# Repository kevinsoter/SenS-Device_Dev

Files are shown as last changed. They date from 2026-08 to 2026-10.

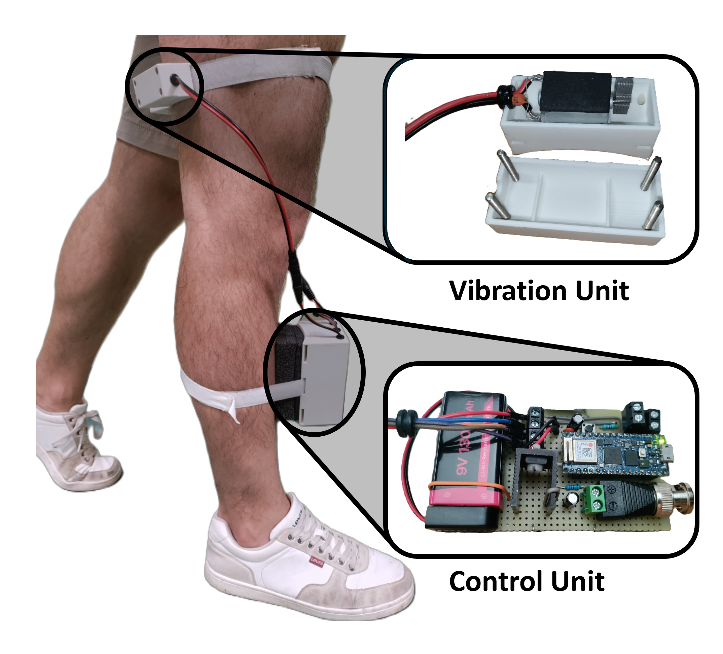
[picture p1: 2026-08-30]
images/SenS-Device.png

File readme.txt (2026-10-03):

A Compact Wearable Tendon Vibration Device for Dynamic Modulation of Proprioceptive Feedback

**Status: Development and validation manuscript in preparation**

This repository will host the open-source hardware, firmware, and design files for a wearable device developed to deliver controlled tendon vibration for eliciting the Tonic Vibration Reflex (TVR) and proprioceptive stimulation of muscle spindles. The device was designed to output vibration at defined frequencies and amplitudes suitable for TVR elicitation, and its development and validation are described in an accompanying manuscript currently in preparation.

## About the Project

Tendon vibration is a well-established technique for eliciting the Tonic Vibration Reflex and proprioceptive illusions by stimulating Ia afferents in muscle spindles. Reliable, low-cost, and reproducible hardware for delivering this stimulation in research appropriate ways is not widely available as an open resource, which motivated the development of this wearable.

The device is designed to:
- Deliver vibration within the frequency and amplitude ranges known to elicit TVR
- Be wearable and adjustable for placement over target tendons/muscle bellies
- Allow researchers to reproduce and adapt the stimulation parameters for their own protocols

Further technical detail, methodology, and validation data will be available once the manuscript is published.

## Planned Repository Contents

The following materials will be added as they are finalized and cleared for release:

- [ ] Paper abstract
- [x] Electronics schematics & routing files
- [x] Materials/Components used
- [x] Firmware (Arduino IDE, C++) for vibration frequency/amplitude Control
- [x] CAD files for the custom enclosure/casing (wearable housing)

## Current Status

| Component | Status |
|---|---|
| Device design | Complete |
| Firmware | Complete |
| Manuscript | In preparation |
| Schematics/CAD release | Pending |
| Validation dataset | Pending publication |

## Why Open Source?

Custom stimulation hardware is a common bottleneck for labs studying proprioception, motor control, and vibrotactile feedback. By releasing the full design, electronics, enclosure, and firmware we hope to lower the barrier for other groups to replicate, adapt, or build on this work.

---

*This README will be updated as the manuscript progresses and files are released. Last updated: [12.07.206].*

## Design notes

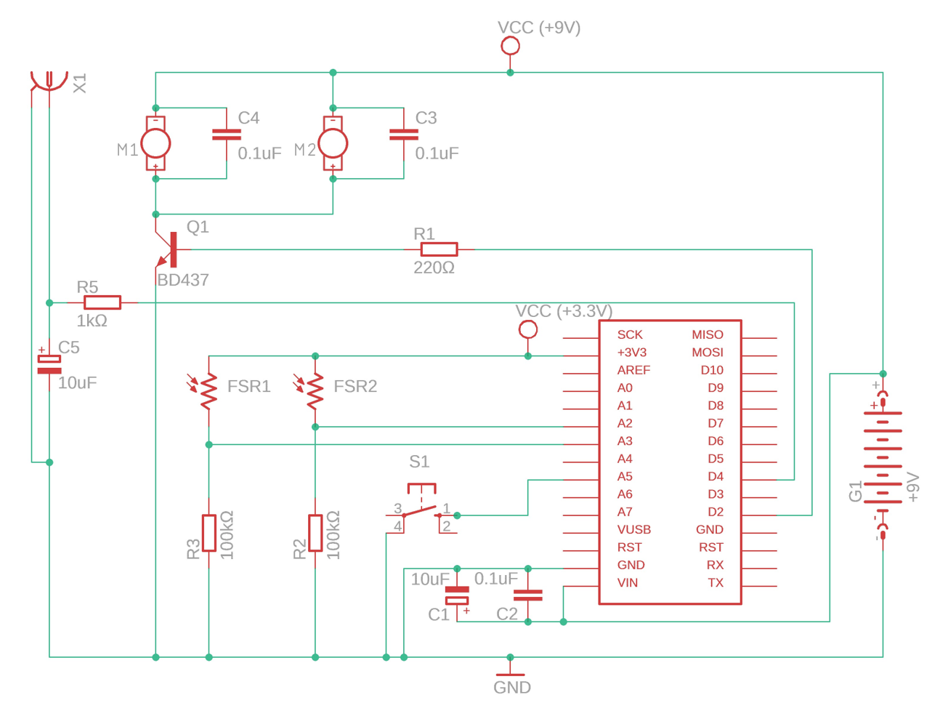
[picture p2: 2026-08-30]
hardware/electronics/SenS_Device_Schematics.png

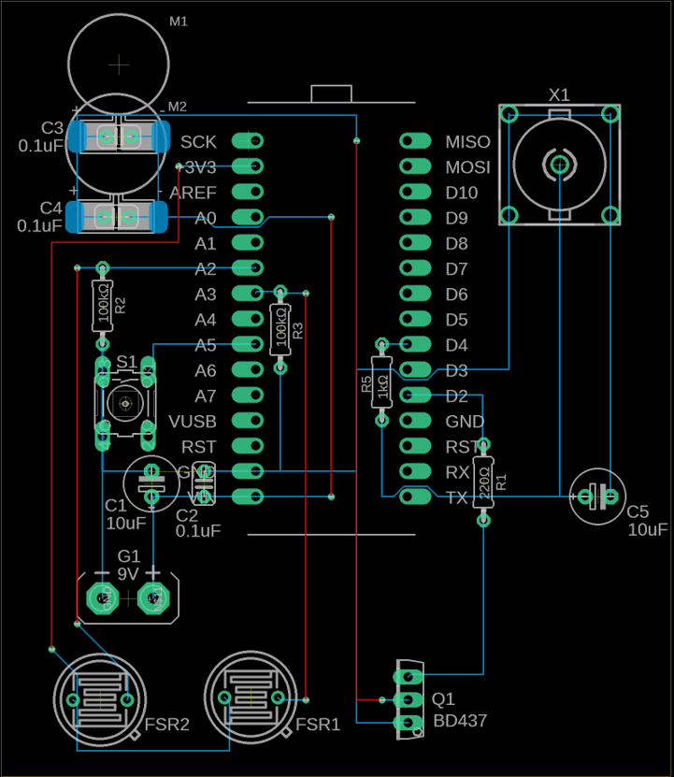
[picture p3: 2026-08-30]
hardware/electronics/SenS_Device_Routing.png

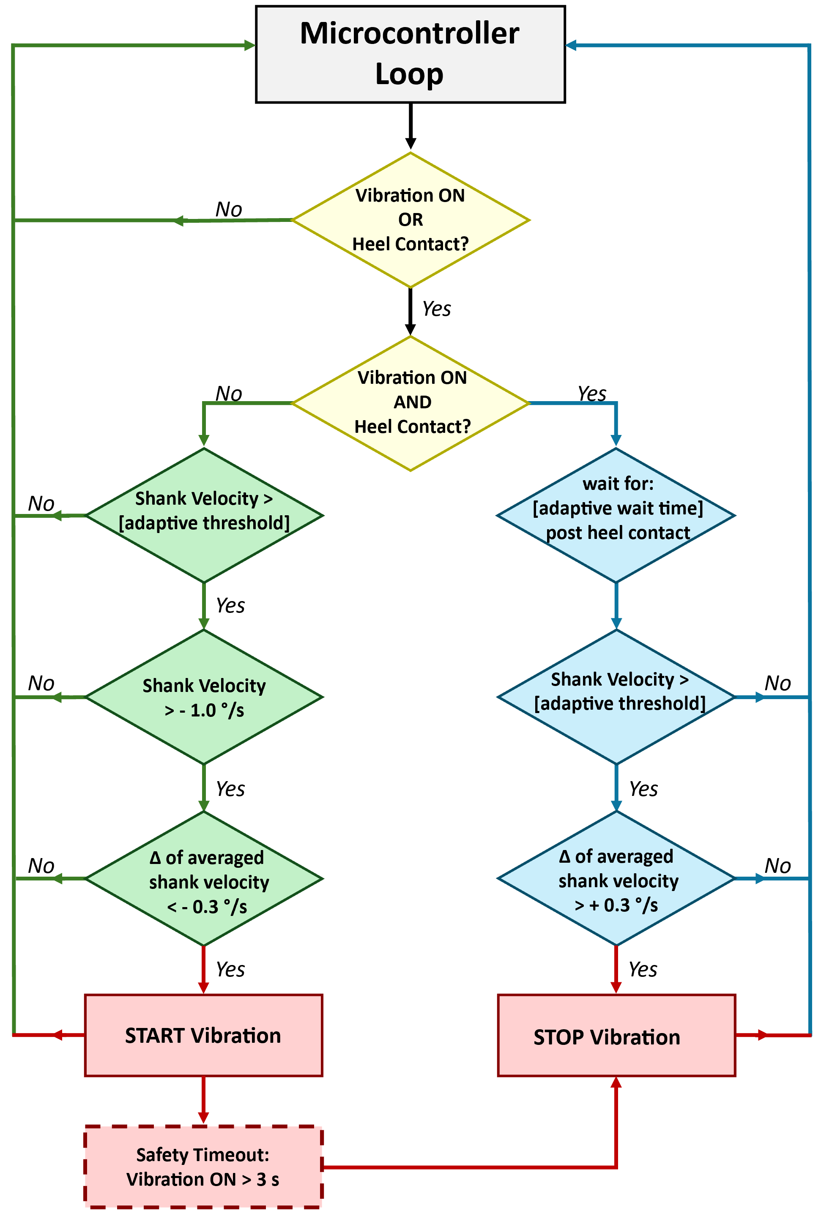
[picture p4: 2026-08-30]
software/gait_control/gait_control_logic_flowchart.png

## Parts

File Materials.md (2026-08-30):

# Materials

This document lists the hardware components used to build the SenS-Device.

## Core electronics

| Qty. | Component | Specification / part number | Manufacturer / source | Notes |
|---:|---|---|---|---|
| 1 | Microcontroller | Arduino Nano RP2040 Connect | Arduino | Main microcontroller |
| 1 | Transistor | BD437, NPN BJT | — | Switches the vibration motors |
| 1 | Resistor | 220 Ω | — | — |
| 2 | Resistor | 100 kΩ | — | — |
| 1 | Resistor | 1 kΩ | — | — |
| 1 | Push button | COM-00097  | Sparkfun | Manual switch for vibration |
| 2 | Capacitor | 10 µF | — | — |
| 1 | Capacitor | 0.1 µF | — | — |

## Sensors and actuators

| Qty. | Component | Specification / part number | Manufacturer / source | Notes |
|---:|---|---|---|---|
| 2 | Force-sensitive resistor (FSR) | — | — | Used for heel contact detection |
| 2 | Eccentric rotating mass (ERM) vibration motor | 320-105 | Precision Microdrives | 20.4 mm diameter × 25 mm length; nominal voltage 3 V |
| 1 | Transistor heatsink | — | — | Mounted to the BD437 |

## Power

| Qty. | Component | Specification / part number | Manufacturer / source | Notes |
|---:|---|---|---|---|
| 1 | Rechargeable battery | 9 V, 1300 mAh | PAISUE / Shenzhen Maxpower Technology Co., Ltd., Shenzhen, China | Main power supply |
| 1 | Battery connector | 9 V battery connection | — | — |

## Connectors

| Qty. | Component | Specification / part number | Notes |
|---:|---|---|---|
| 1 | BNC connector | Straight, screw connection, product no. 76738 | Used for external synchronization |
| 4 | Female-to-male header connector | 2-pin | Used to mount the Arduino to the perfboard while keeping it removable |
| 2 | Female-to-male header connector | 1-pin | Used for removable Arduino/perfboard connection |
| 1 | Female-to-male header connector | 4-pin | Used for removable Arduino/perfboard connection |
| 1 | Female-to-male header connector | 3-pin | Used for removable Arduino/perfboard connection |
| 4 | Screw terminal / cable connector | Exact type/part number not recorded | — |

## Mechanical hardware

| Qty. | Component | Specification | Notes |
|---:|---|---|---|
| 1 | Screw | M3 | Heatsink mounting |
| 1 | Nut | M3 | Heatsink mounting |

## Reference documentation

- [Arduino Nano RP2040 Connect — official product page](https://store-usa.arduino.cc/collections/interactive-games/products/arduino-nano-rp2040-connect)
- [Precision Microdrives 320-105 — official product page](https://precisionmicrodrives.com/products/4d033395-ce29-4dc2-a324-a3c4ccfe9e42/320-105-20mm-vibration-motor-25mm-type)

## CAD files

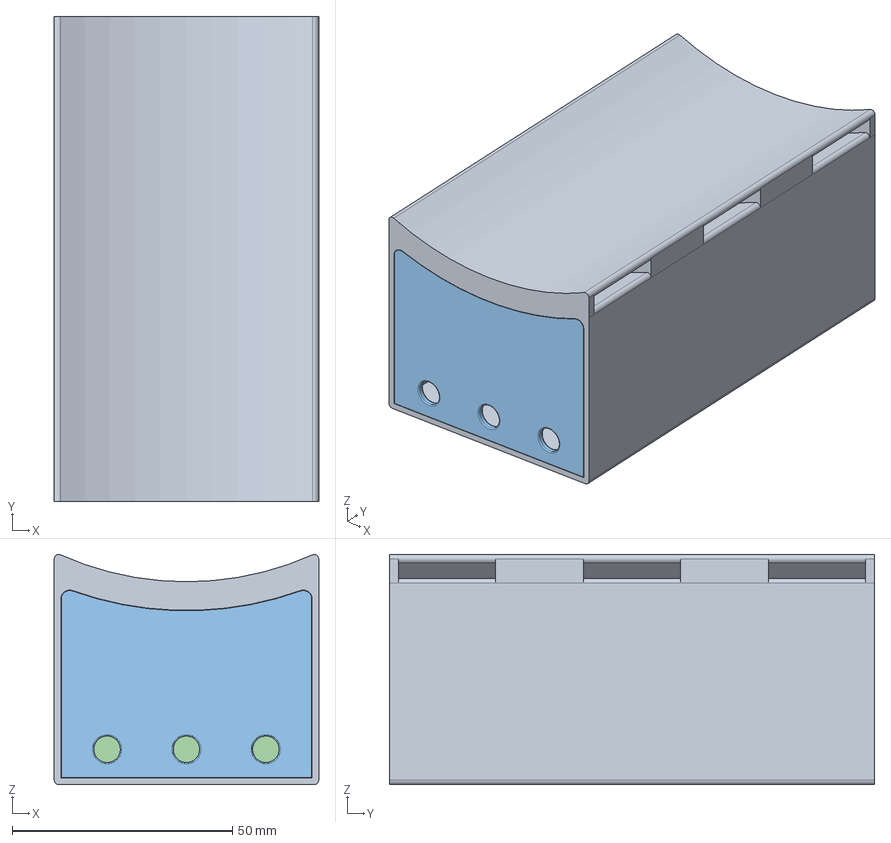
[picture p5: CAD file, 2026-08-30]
hardware/CAD/SenS_Encasing_ControlUnit.step
60.0 x 110.0 x 52.2 mm

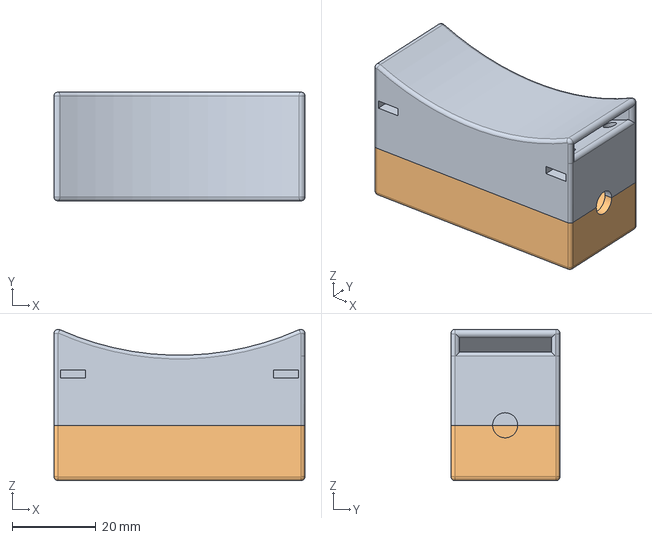
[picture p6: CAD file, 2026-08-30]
hardware/CAD/SenS_Encasing_VibrationUnit.step
60.0 x 26.0 x 36.2 mm

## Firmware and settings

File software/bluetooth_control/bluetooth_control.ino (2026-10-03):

// __________________________________________________________//
// Arduino code for manual control of vibration frequency    //
// of the SenS-Device using bluetooth of the Ardino          //
// In addition the analog output sends a 3V-Out signal       //
// when the vibration starts, lasting the entire duration    //
// of the vibration. No contact to the PC is needed.         //
// ~80 Hz at 200 decimal, which equals C8 in hexadecimal     //                             
//                                                           //
//___________________________________________________________//

#include <Wire.h>
#include <ArduinoBLE.h>

//_Fill in by hand_//

u_int32_t waitTime = 1000;                              // time to wait before vibrating in miliseconds
u_int32_t vibTime = 5000;                               // in miliseconds

//______END_______ // 

const int motor_pin = 2;
const int anOutput = 4;
int vib_var = 0;
u_int32_t timer = 0;
u_int32_t wait_timer = 0;

// BLE LED Switch Characteristic - custom 128-bit UUID, read and writable by central
BLEService ledService("180A");                          // BLE LED Service
BLEByteCharacteristic switchCharacteristic("2A57", BLERead | BLEWrite);

void setup() {

  pinMode(anOutput, OUTPUT);

  // Initialize BLE
  if (!BLE.begin()) {
    while (1);
  }

  BLE.setLocalName("Nano rp 2040");                   // Name found in App when connecting to bluetooth
  BLE.setAdvertisedService(ledService);               // Set service UUID
  ledService.addCharacteristic(switchCharacteristic); // Add the characteristic to the service
  BLE.addService(ledService);                         // Add service
  switchCharacteristic.writeValue(0);                 // Set the initial value for the characteristic:
  BLE.advertise();                                    // Start advertising

}

void loop() {
  
  BLEDevice central = BLE.central();                  // Listen for Bluetooth peripherals to connect:

  if (switchCharacteristic.value() == 1) {
    timer = millis();
    while(millis() - timer <= vibTime) {              // Vibrating for the  duration of vibTime
      analogWrite(motor_pin, 125);                    // If sending "1" to device it starts at 125
      analogWrite(anOutput, 255);                     // Starting vibration sends out 3V signal through analog
    }
    switchCharacteristic.writeValue(0);
  }

  else if (switchCharacteristic.written() && switchCharacteristic.value() != 1 && switchCharacteristic.value() != 0) {
    wait_timer = millis();
    while(millis() - wait_timer <= waitTime) {
      analogWrite(anOutput, 127);
    }
    timer = millis();
    while(millis() - timer <= vibTime) {              // Vibrating for the  duration of vibTime
      analogWrite(motor_pin, switchCharacteristic.value()); // Vibrating at intensity sent vie bluetooth (in hexadecimal)
      analogWrite(anOutput, 255);                     // Starting vibration sends out 3V signal through analog
    }
    switchCharacteristic.writeValue(0);
  }

  else {                                             // No Vibration
    analogWrite(motor_pin, 0);
    analogWrite(anOutput, 85);
  }

}

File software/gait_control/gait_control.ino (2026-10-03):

// __________________________________________________________//
// Arduino code for vibration of SenS-Device during gait     //
// using an IMU and pressure sensor. The Arduino controls    //
// the vibration based on shank movement and heel contact    //
// to control the start and stop timing.                     //
// ~ 80 Hz vibration fs = duty cycle 200 decimal
//                                                           //
// Start vibration: Sagittal shank angular velocity (Gy)     //
//                  is taken from the gyroscope. This data   //
//                  is filtered using a 30-sample moving     //
//                  average. The peak extension after        //
//                  toe-off is detected and used to send     //
//                  the onset signal.                        //
//                                                           //
// Stop vibration:  The same data is used to detect the peak //
//                  flexion during ground contact, which     //
//                  happens shortly before the actual toe-   //
//                  off. This then sends the offset signal.  //
//                                                           //
// __________________________________________________________//

#include <Wire.h>
#include <Adafruit_LSM6DSOX.h>

// FILL IN BY HAND //

u_int32_t vibr = 200;       // Duty Cycle (Decimals: 0-255)

//____END________//

Adafruit_LSM6DSOX sox;      // Defining the handle for the IMU

u_int32_t motor_pin = 2;    // Pin used for vibration (PWM signal to open/close transistor)
u_int32_t anOutput = 4;     // Pin sends analog output to DAQ
u_int32_t heel_pin = A3;    // Pin for FSR reading of heel contact

float heel_reading;         // Variable to store FSR value
float peak_vel;
float threshold_wait = 400; // Only initial value
float threshold_vel = 75;   // Only initial value

u_int32_t timer_heel;       // Variable to store the time since the last heel contact
u_int32_t vibr_timer;       // Variable to store time since vibration started

bool firstContact = false;    // Bool for first heel contact in gait cycle
bool vibr_status = false;     // Bool for status of vibration
bool start_searching = false; // Bool for the start of searching conditions for vibration start
bool start_searching2 = false;
bool stop_searching = false;
bool stop_searching2 = false;
bool peak_vel_flag = false;

// Variables needed for gyroscope calibration
int RateCalibrationNumber;
float RateCalibrationY;

float Gx, Gy, Gz;
float Gy_avg, Gy_avg_old;

float Gy_old = 1000;
float stop_val = 0;

// Function to retrieve the IMU value
void IMU_signals(void) {

  sensors_event_t accel;
  sensors_event_t gyro;
  sensors_event_t temp;

  sox.getEvent(&accel, &gyro, &temp);

  Gy = gyro.gyro.y * 1 / (3.142 / 180);
}

float movingAverage(float value) {
  const byte nvalues = 30;             // Moving average window size

  static byte current = 0;             // Index for current value
  static byte cvalues = 0;             // Count of values read (<= nvalues)
  static float sum = 0;                // Rolling sum
  static float values[nvalues];

  sum += value;

  if (cvalues == nvalues)
    sum -= values[current];

  values[current] = value;

  if (++current >= nvalues)
    current = 0;

  if (cvalues < nvalues)
    cvalues += 1;

  return sum / cvalues;
}

void setup(void) {

  if (!sox.begin_I2C()) {
    while (1);
  }

  sox.setAccelRange(LSM6DS_ACCEL_RANGE_8_G);
  sox.setGyroRange(LSM6DS_GYRO_RANGE_2000_DPS);
  sox.setAccelDataRate(LSM6DS_RATE_6_66K_HZ);
  sox.setGyroDataRate(LSM6DS_RATE_6_66K_HZ);

  for (RateCalibrationNumber = 0; RateCalibrationNumber < 2000; RateCalibrationNumber++) {
    IMU_signals();
    RateCalibrationY += Gy;
    delay(1);
  }

  RateCalibrationY /= 2000;

  pinMode(heel_pin, INPUT);
  pinMode(anOutput, OUTPUT);
  pinMode(motor_pin, OUTPUT);

  analogWrite(motor_pin, 0);
}

void loop() {

  IMU_signals();
  heel_reading = analogRead(heel_pin);

  Gy_avg_old = Gy_avg;

  Gy -= RateCalibrationY;
  Gy_avg = movingAverage(Gy);

  //____Find Vibration Onset___//

  if (vibr_status == false &&
      start_searching == false &&
      firstContact == false &&
      Gy > threshold_vel) {

    start_searching = true;
  }

  if (start_searching == true &&
      start_searching2 == false &&
      Gy < -1.0) {

    start_searching2 = true;
    start_searching = false;
  }

  if (start_searching2 == true &&
      Gy_avg_old - Gy_avg < -0.3) {

    vibr_status = true;
    start_searching2 = false;
    peak_vel_flag = true;
    vibr_timer = micros();
  }

  if (peak_vel_flag == true) {

    peak_vel = abs(Gy_avg);
    threshold_wait = 1000 / peak_vel * 100;
    threshold_vel = peak_vel / 3.5;

    peak_vel_flag = false;
  }

  //____Find Vibration Offset___//

  if (vibr_status == true &&
      stop_searching == false &&
      firstContact == true &&
      micros() - timer_heel >= threshold_wait * 1000) {

    stop_searching = true;
  }

  if (stop_searching == true &&
      stop_searching2 == false &&
      Gy > threshold_vel) {

    stop_searching2 = true;
    stop_searching = false;
  }

  if (stop_searching2 == true &&
      Gy_avg - Gy_avg_old < -0.3) {

    vibr_status = false;
    stop_searching2 = false;
  }

  if (vibr_status == true) {

    analogWrite(motor_pin, vibr);
    analogWrite(anOutput, 170);

  } else {

    analogWrite(motor_pin, 0);
    analogWrite(anOutput, 85);
  }

  //____Maximum vibration duration___//

  if (vibr_status == true &&
      micros() - vibr_timer >= 3000 * 1000) {

    vibr_status = false;
  }

  //____Heel Contact___//

  if (heel_reading > 950 &&
      firstContact == false) {

    firstContact = true;
    timer_heel = micros();
  }

  if (micros() - timer_heel >= threshold_wait * 1000 &&
      heel_reading < 400) {

    firstContact = false;
  }
}
